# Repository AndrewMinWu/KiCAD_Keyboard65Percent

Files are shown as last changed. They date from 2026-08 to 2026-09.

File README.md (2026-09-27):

# Custom 65% Keyboard PCB





Untitled design

## Repository Structure

```text
├── Hardware/          # Schematic, PCB, and gerber files
├── Firmware/          # Firmware files
└── Libraries_And_Datasheets/              # Datasheets and libraries (from ai03) for keyboard parts. 
```

## Purpose & Motivation

When I was 15, I bought my first custom mechanical keyboard: a QK60 from Qwertykeys alongside Gateron yellow switches and some cheap keycaps from amazon. However, I encountered a problem when I accidently took out the PCB with the JST connector still plugged in, ripping the socket on the daughterboard (where the usb-c was). Devastated, this experience essentially brought me into PCB design through online guides and communities. 2 years later, with more PCB design experience, I decided to create my own 65% keyboard (my personal favorite form factor. Who uses the numpad anyways!?).     

## Design

### Component List (BOM)
1. ATmega32U4 8-bit AVR Microcontroller ([Datasheet](http://ww1.microchip.com/downloads/en/DeviceDoc/Atmel-7766-8-bit-AVR-ATmega16U4-32U4_Datasheet.pdf))
2. ECS-160 16.000MHz SMD Crystal 3225 4-Pin ([Datasheet](https://ecsxtal.com/store/pdf/ECX-32.pdf))
3. GCT USB4105-GF-A USB-C Receptacle 16P SMD RA ([Datasheet](https://gct.co/files/drawings/usb4105.pdf))
4. Keyboard Switches (MX, taken from ai03's library)
5. 1N4148 / 1N4148W Switching Diodes
6. Passives & Miscellaneous Hardware:
   - Capacitors (0805, Ceramic)
   - Resistors (0805)
   - Tactile Push Button (Reset Switch)

### PCB, Schematic, 3D Render

The full PCB was designed with KiCAD






## Firmware

The firmware for this keyboard is built using QMK. While the framework is C-based, configuring the board primarily involved utilizing the standard QMK file structure to define the hardware and layout:
* **`info.json` & `config.h`:** Keyboard matrix, MCU definitions, and hardware config
* **`rules.mk`:** Bootloader selection
* **`keymap.c`:** Keymap and layer definitions (able to change config with VIA)

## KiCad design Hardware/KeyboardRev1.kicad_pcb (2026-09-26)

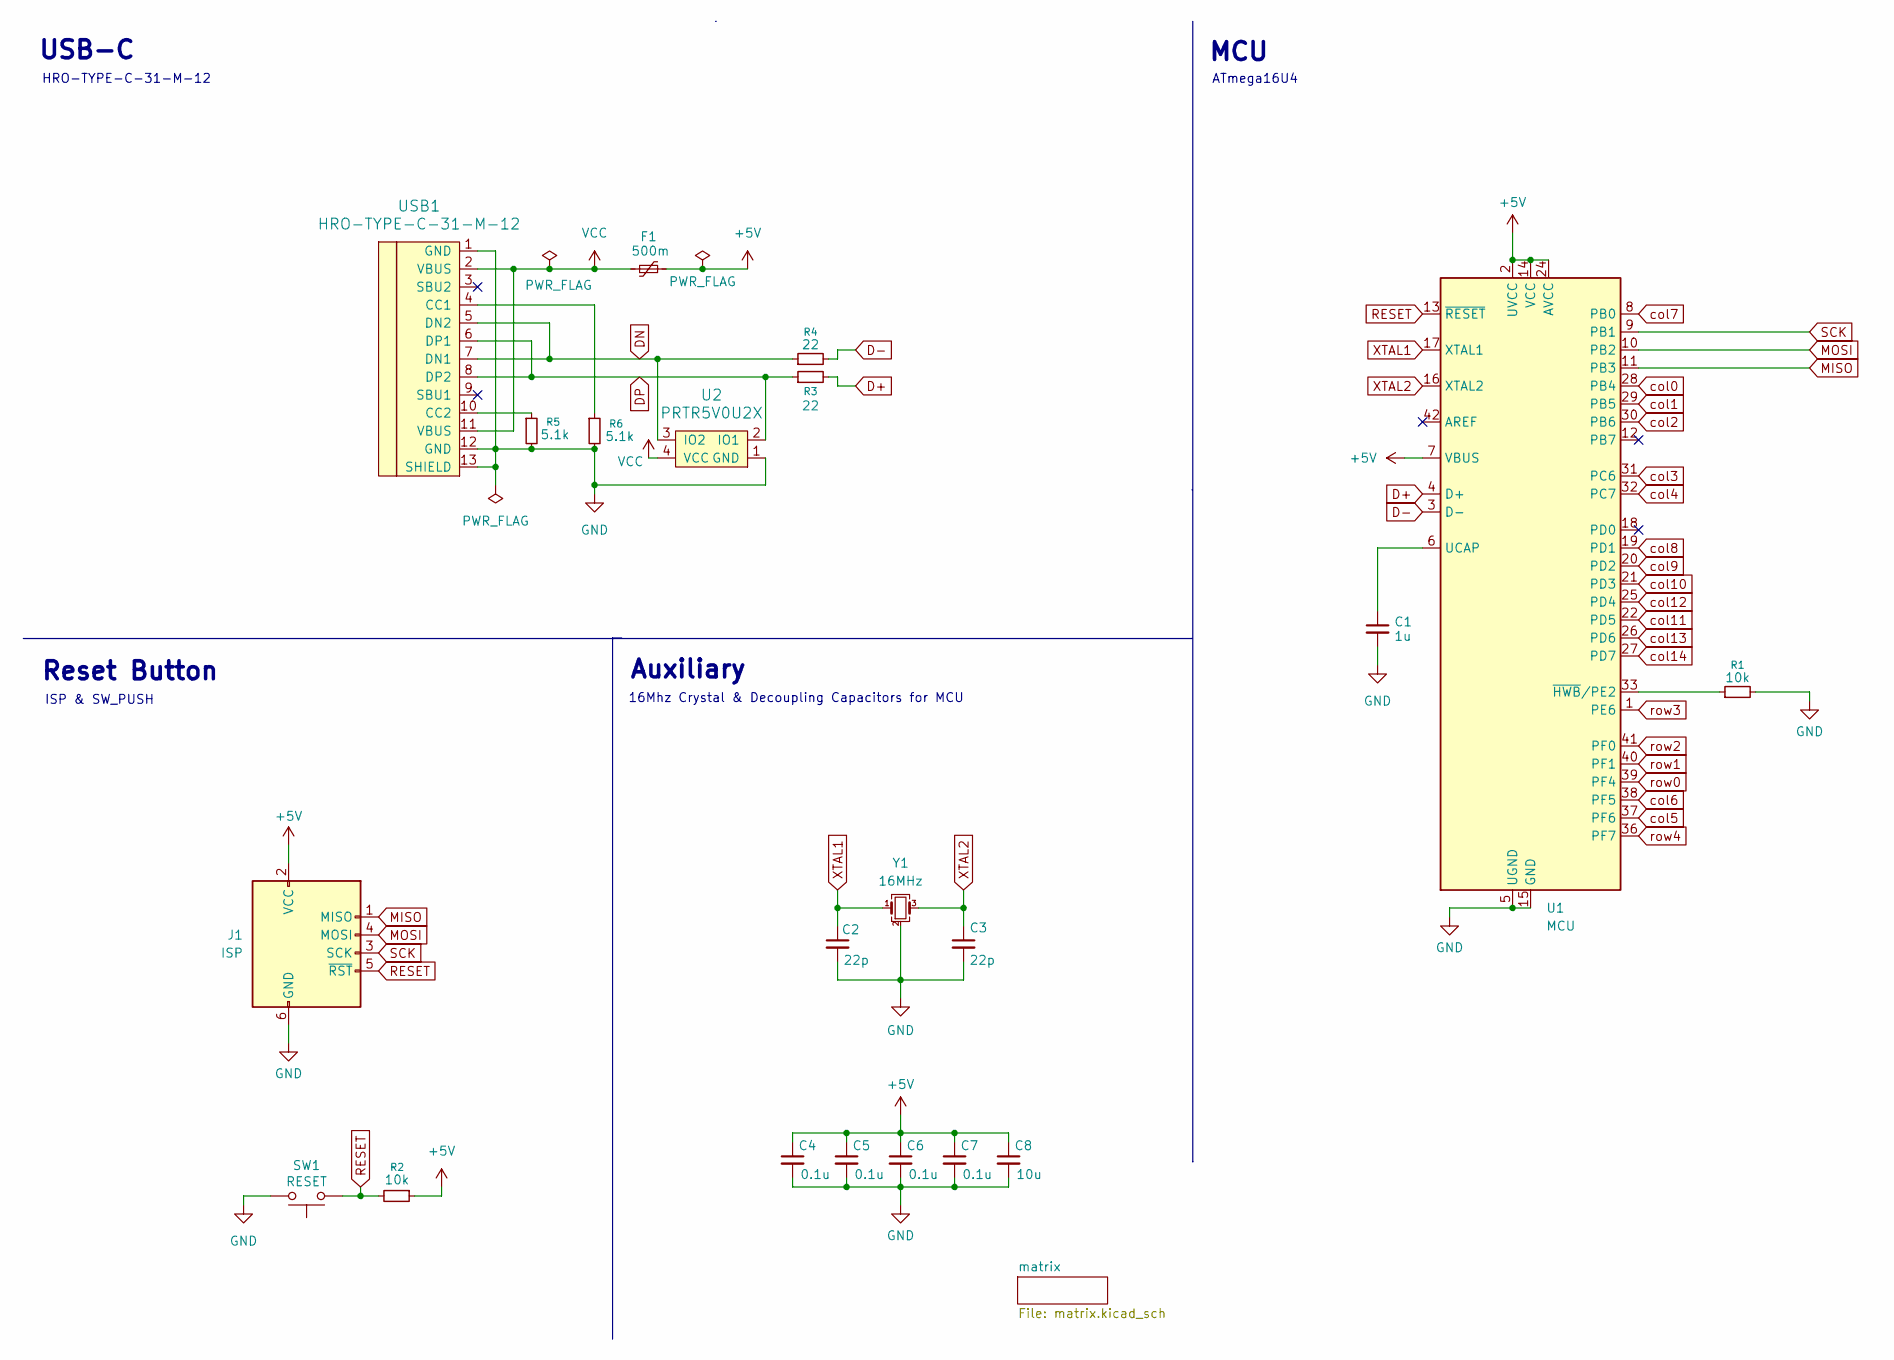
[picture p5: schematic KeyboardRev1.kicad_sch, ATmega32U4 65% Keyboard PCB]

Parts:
C1: 1u; C_0805_2012Metric_Pad1.18x1.45mm_HandSolder
C2, C3: 22p; C_0805_2012Metric_Pad1.18x1.45mm_HandSolder
C4, C5, C6, C7: 0.1u; C_0805_2012Metric_Pad1.18x1.45mm_HandSolder
C8: 10u; C_0805_2012Metric_Pad1.18x1.45mm_HandSolder
F1: 500m; Fuse_1206_3216Metric_Pad1.42x1.75mm_HandSolder
J1: ISP; Reset_Pretty-Mask
R1, R2: 10k; R_0805_2012Metric_Pad1.20x1.40mm_HandSolder
R3, R4: 22; R_0805_2012Metric_Pad1.20x1.40mm_HandSolder
R5, R6: 5.1k; R_0805_2012Metric_Pad1.20x1.40mm_HandSolder
SW1: RESET; SW_SPST_SKQG_WithStem
U1: MCU; TQFP-44_10x10mm_P0.8mm
U2: PRTR5V0U2X; SOT143B
USB1: HRO-TYPE-C-31-M-12; HRO-TYPE-C-31-M-12-HandSoldering
Y1: 16MHz; Crystal_SMD_3225-4Pin_3.2x2.5mm_HandSoldering

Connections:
+5V: C4.1, C5.1, C6.1, C7.1, C8.1, F1.2, J1.2 (VCC), R2.1, U1.2 (UVCC), U1.7 (VBUS), U1.14 (VCC), U1.24 (AVCC), U1.34 (VCC), U1.44 (AVCC)
D+: R3.2, U1.4 (D+)
D-: R4.2, U1.3 (D-)
DN: R4.1, U2.3 (IO2), USB1.5 (DN2), USB1.7 (DN1)
DP: R3.1, U2.2 (IO1), USB1.6 (DP1), USB1.8 (DP2)
GND: C1.2, C2.2, C3.2, C4.2, C5.2, C6.2, C7.2, C8.2, J1.6 (GND), R1.2, R5.2, R6.2, SW1.2, U1.5 (UGND), U1.15 (GND), U1.23 (GND), U1.35 (GND), U1.43 (GND), U2.1 (GND), USB1.1 (GND), USB1.12 (GND), USB1.13 (SHIELD), Y1.2 (G), Y1.4 (G)
MISO: J1.1 (MISO), U1.11 (PB3)
MOSI: J1.4 (MOSI), U1.10 (PB2)
unnamed: C1.1, U1.6 (UCAP)
unnamed: R1.1, U1.33 (~HWB/PE2)
unnamed: R6.1, USB1.4 (CC1)
unnamed: R5.1, USB1.10 (CC2)
RESET: J1.5 (~RST), R2.2, SW1.1, U1.13 (~RESET)
SCK: J1.3 (SCK), U1.9 (PB1)
VCC: F1.1, U2.4 (VCC), USB1.2 (VBUS), USB1.11 (VBUS)
XTAL1: C2.1, U1.17 (XTAL1), Y1.1
XTAL2: C3.1, U1.16 (XTAL2), Y1.3
col0: U1.28 (PB4); also elsewhere on the board
col1: U1.29 (PB5); also elsewhere on the board
col2: U1.30 (PB6); also elsewhere on the board
col3: U1.31 (PC6); also elsewhere on the board
col4: U1.32 (PC7); also elsewhere on the board
col5: U1.37 (PF6); also elsewhere on the board
col6: U1.38 (PF5); also elsewhere on the board
col7: U1.8 (PB0); also elsewhere on the board
col8: U1.19 (PD1); also elsewhere on the board
col9: U1.20 (PD2); also elsewhere on the board
col10: U1.21 (PD3); also elsewhere on the board
col11: U1.22 (PD5); also elsewhere on the board
col12: U1.25 (PD4); also elsewhere on the board
col13: U1.26 (PD6); also elsewhere on the board
col14: U1.27 (PD7); also elsewhere on the board
row0: U1.39 (PF4); also elsewhere on the board
row1: U1.40 (PF1); also elsewhere on the board
row2: U1.41 (PF0); also elsewhere on the board
row3: U1.1 (PE6); also elsewhere on the board
row4: U1.36 (PF7); also elsewhere on the board

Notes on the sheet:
16Mhz Crystal & Decoupling Capacitors for MCU
ATmega16U4
ISP & SW_PUSH
HRO-TYPE-C-31-M-12
Reset Button
USB-C
MCU
Auxiliary

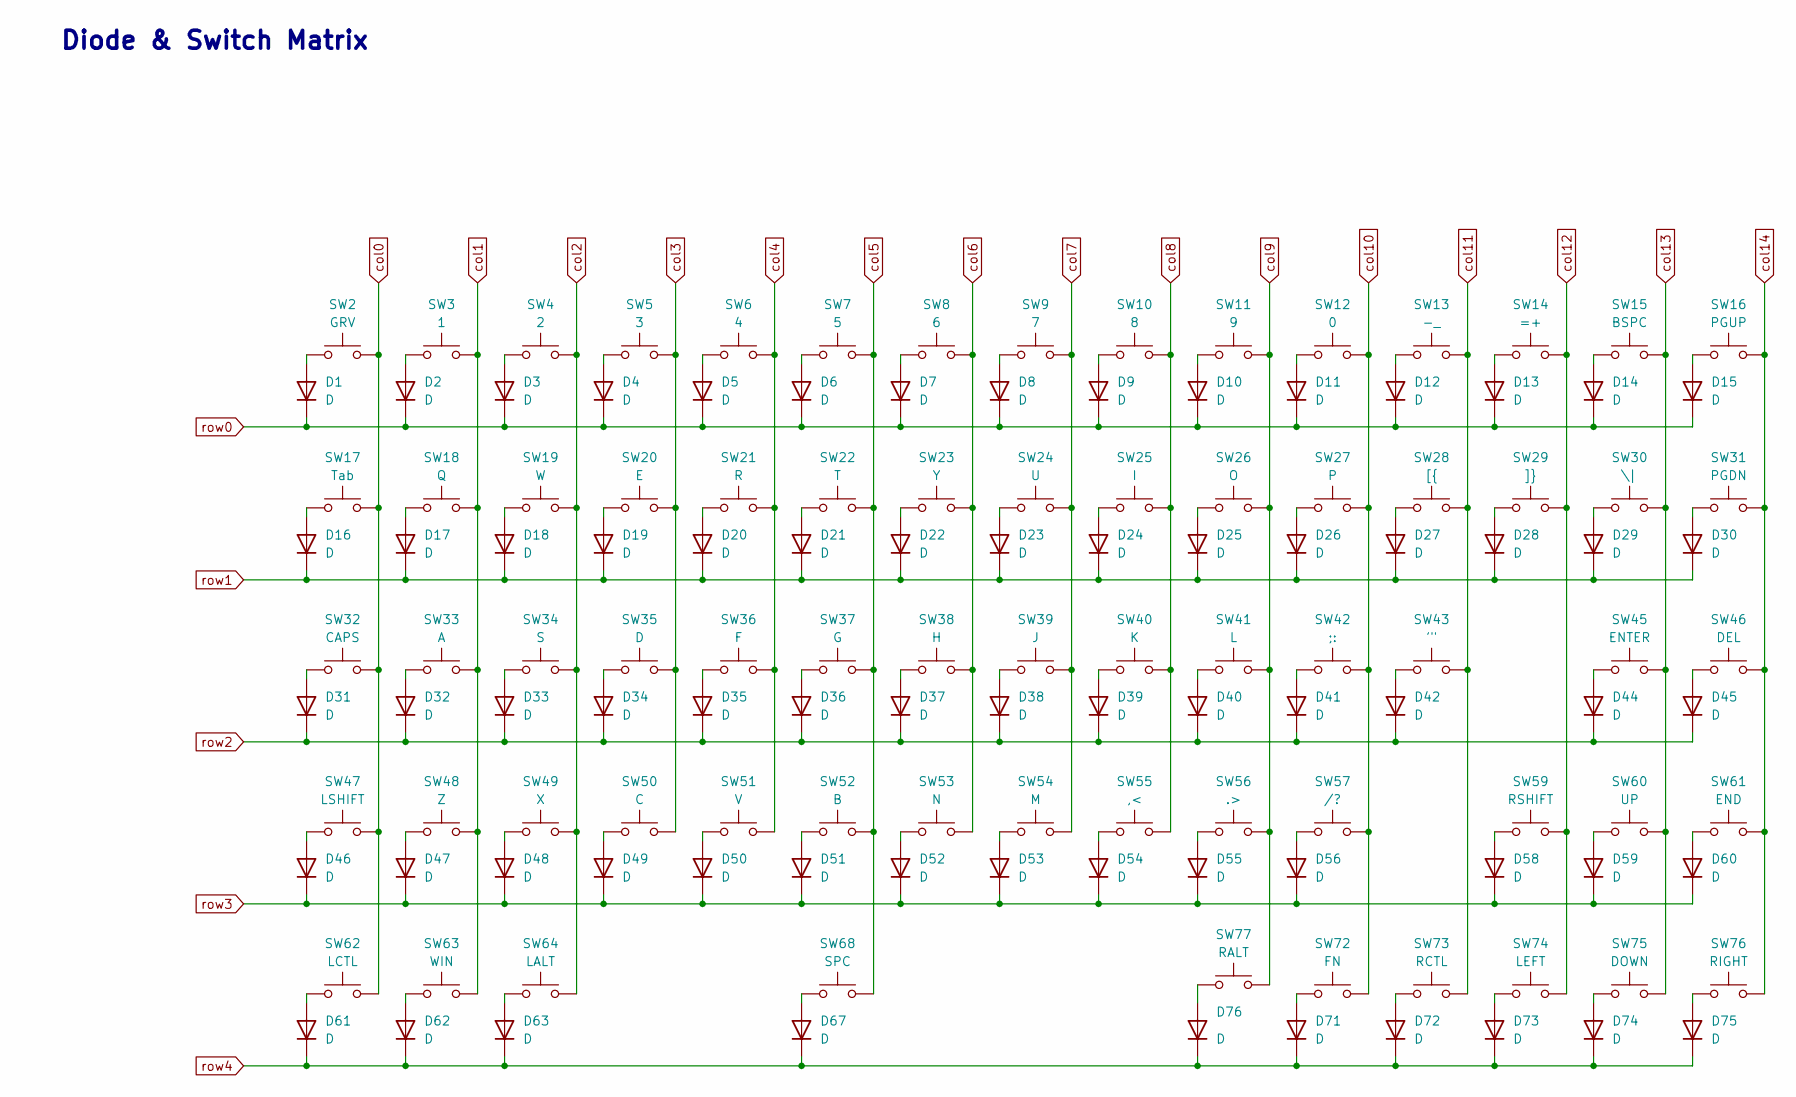
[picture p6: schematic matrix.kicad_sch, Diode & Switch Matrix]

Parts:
D1, D2, D3, D4, D5, D6, D7, D8, D9, D10, D11, D12, D13, D14, D15, D16, D17, D18, D19, D20, D21, D22, D23, D24, D25, D26, D27, D28, D29, D30, D31, D32, D33, D34, D35, D36, D37, D38, D39, D40, D41, D42, D44, D45, D46, D47, D48, D49, D50, D51, D52, D53, D54, D55, D56, D58, D59, D60, D61, D62, D63, D67, D71, D72, D73, D74, D75, D76: D; D_SOD-123
SW2: GRV; SW_Cherry_MX_1.00u_PCB
SW3: 1; SW_Cherry_MX_1.00u_PCB
SW4: 2; SW_Cherry_MX_1.00u_PCB
SW5: 3; SW_Cherry_MX_1.00u_PCB
SW6: 4; SW_Cherry_MX_1.00u_PCB
SW7: 5; SW_Cherry_MX_1.00u_PCB
SW8: 6; SW_Cherry_MX_1.00u_PCB
SW9: 7; SW_Cherry_MX_1.00u_PCB
SW10: 8; SW_Cherry_MX_1.00u_PCB
SW11: 9; SW_Cherry_MX_1.00u_PCB
SW12: 0; SW_Cherry_MX_1.00u_PCB
SW13: -_; SW_Cherry_MX_1.00u_PCB
SW14: =+; SW_Cherry_MX_1.00u_PCB
SW15: BSPC; SW_Cherry_MX_2.00u_PCB
SW16: PGUP; SW_Cherry_MX_1.00u_PCB
SW17: Tab; SW_Cherry_MX_1.50u_PCB
SW18: Q; SW_Cherry_MX_1.00u_PCB
SW19: W; SW_Cherry_MX_1.00u_PCB
SW20: E; SW_Cherry_MX_1.00u_PCB
SW21: R; SW_Cherry_MX_1.00u_PCB
SW22: T; SW_Cherry_MX_1.00u_PCB
SW23: Y; SW_Cherry_MX_1.00u_PCB
SW24: U; SW_Cherry_MX_1.00u_PCB
SW25: I; SW_Cherry_MX_1.00u_PCB
SW26: O; SW_Cherry_MX_1.00u_PCB
SW27: P; SW_Cherry_MX_1.00u_PCB
SW28: [{; SW_Cherry_MX_1.00u_PCB
SW29: ]}; SW_Cherry_MX_1.00u_PCB
SW30: \|; SW_Cherry_MX_1.50u_PCB
SW31: PGDN; SW_Cherry_MX_1.00u_PCB
SW32: CAPS; SW_Cherry_MX_1.75u_PCB
SW33: A; SW_Cherry_MX_1.00u_PCB
SW34: S; SW_Cherry_MX_1.00u_PCB
SW35: D; SW_Cherry_MX_1.00u_PCB
SW36: F; SW_Cherry_MX_1.00u_PCB
SW37: G; SW_Cherry_MX_1.00u_PCB
SW38: H; SW_Cherry_MX_1.00u_PCB
SW39: J; SW_Cherry_MX_1.00u_PCB
SW40: K; SW_Cherry_MX_1.00u_PCB
SW41: L; SW_Cherry_MX_1.00u_PCB
SW42: ;:; SW_Cherry_MX_1.00u_PCB
SW43: '"; SW_Cherry_MX_1.00u_PCB
SW45: ENTER; SW_Cherry_MX_2.25u_PCB
SW46: DEL; SW_Cherry_MX_1.00u_PCB
SW47: LSHIFT; SW_Cherry_MX_2.25u_PCB
SW48: Z; SW_Cherry_MX_1.00u_PCB
SW49: X; SW_Cherry_MX_1.00u_PCB
SW50: C; SW_Cherry_MX_1.00u_PCB
SW51: V; SW_Cherry_MX_1.00u_PCB
SW52: B; SW_Cherry_MX_1.00u_PCB
SW53: N; SW_Cherry_MX_1.00u_PCB
SW54: M; SW_Cherry_MX_1.00u_PCB
SW55: ,<; SW_Cherry_MX_1.00u_PCB
SW56: .>; SW_Cherry_MX_1.00u_PCB
SW57: /?; SW_Cherry_MX_1.00u_PCB
SW59: RSHIFT; SW_Cherry_MX_1.75u_PCB
SW60: UP; SW_Cherry_MX_1.00u_PCB
SW61: END; SW_Cherry_MX_1.00u_PCB
SW62: LCTL; SW_Cherry_MX_1.25u_PCB
SW63: WIN; SW_Cherry_MX_1.25u_PCB
SW64: LALT; SW_Cherry_MX_1.25u_PCB
SW68: SPC; SW_Cherry_MX_6.25u_PCB
SW72: FN; SW_Cherry_MX_1.00u_PCB
SW73: RCTL; SW_Cherry_MX_1.00u_PCB
SW74: LEFT; SW_Cherry_MX_1.00u_PCB
SW75: DOWN; SW_Cherry_MX_1.00u_PCB
SW76: RIGHT; SW_Cherry_MX_1.00u_PCB
SW77: RALT; SW_Cherry_MX_1.00u_PCB

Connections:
unnamed: D1.2 (A), SW2.1
unnamed: D2.2 (A), SW3.1
unnamed: D3.2 (A), SW4.1
unnamed: D4.2 (A), SW5.1
unnamed: D5.2 (A), SW6.1
unnamed: D6.2 (A), SW7.1
unnamed: D7.2 (A), SW8.1
unnamed: D8.2 (A), SW9.1
unnamed: D9.2 (A), SW10.1
unnamed: D10.2 (A), SW11.1
unnamed: D11.2 (A), SW12.1
unnamed: D12.2 (A), SW13.1
unnamed: D13.2 (A), SW14.1
unnamed: D14.2 (A), SW15.1
unnamed: D15.2 (A), SW16.1
unnamed: D16.2 (A), SW17.1
unnamed: D17.2 (A), SW18.1
unnamed: D18.2 (A), SW19.1
unnamed: D19.2 (A), SW20.1
unnamed: D20.2 (A), SW21.1
unnamed: D21.2 (A), SW22.1
unnamed: D22.2 (A), SW23.1
unnamed: D23.2 (A), SW24.1
unnamed: D24.2 (A), SW25.1
unnamed: D25.2 (A), SW26.1
unnamed: D26.2 (A), SW27.1
unnamed: D27.2 (A), SW28.1
unnamed: D28.2 (A), SW29.1
unnamed: D29.2 (A), SW30.1
unnamed: D30.2 (A), SW31.1
unnamed: D31.2 (A), SW32.1
unnamed: D32.2 (A), SW33.1
unnamed: D33.2 (A), SW34.1
unnamed: D34.2 (A), SW35.1
unnamed: D35.2 (A), SW36.1
unnamed: D36.2 (A), SW37.1
unnamed: D37.2 (A), SW38.1
unnamed: D38.2 (A), SW39.1
unnamed: D39.2 (A), SW40.1
unnamed: D40.2 (A), SW41.1
unnamed: D41.2 (A), SW42.1
unnamed: D42.2 (A), SW43.1
unnamed: D44.2 (A), SW45.1
unnamed: D45.2 (A), SW46.1
unnamed: D46.2 (A), SW47.1
unnamed: D47.2 (A), SW48.1
unnamed: D48.2 (A), SW49.1
unnamed: D49.2 (A), SW50.1
unnamed: D50.2 (A), SW51.1
unnamed: D51.2 (A), SW52.1
unnamed: D52.2 (A), SW53.1
unnamed: D53.2 (A), SW54.1
unnamed: D54.2 (A), SW55.1
unnamed: D55.2 (A), SW56.1
unnamed: D56.2 (A), SW57.1
unnamed: D58.2 (A), SW59.1
unnamed: D59.2 (A), SW60.1
unnamed: D60.2 (A), SW61.1
unnamed: D61.2 (A), SW62.1
unnamed: D62.2 (A), SW63.1
unnamed: D63.2 (A), SW64.1
unnamed: D67.2 (A), SW68.1
unnamed: D71.2 (A), SW72.1
unnamed: D72.2 (A), SW73.1
unnamed: D73.2 (A), SW74.1
unnamed: D74.2 (A), SW75.1
unnamed: D75.2 (A), SW76.1
unnamed: D76.2 (A), SW77.1
col0: SW2.2, SW17.2, SW32.2, SW47.2, SW62.2; also elsewhere on the board
col1: SW3.2, SW18.2, SW33.2, SW48.2, SW63.2; also elsewhere on the board
col2: SW4.2, SW19.2, SW34.2, SW49.2, SW64.2; also elsewhere on the board
col3: SW5.2, SW20.2, SW35.2, SW50.2; also elsewhere on the board
col4: SW6.2, SW21.2, SW36.2, SW51.2; also elsewhere on the board
col5: SW7.2, SW22.2, SW37.2, SW52.2, SW68.2; also elsewhere on the board
col6: SW8.2, SW23.2, SW38.2, SW53.2; also elsewhere on the board
col7: SW9.2, SW24.2, SW39.2, SW54.2; also elsewhere on the board
col8: SW10.2, SW25.2, SW40.2, SW55.2; also elsewhere on the board
col9: SW11.2, SW26.2, SW41.2, SW56.2, SW77.2; also elsewhere on the board
col10: SW12.2, SW27.2, SW42.2, SW57.2, SW72.2; also elsewhere on the board
col11: SW13.2, SW28.2, SW43.2, SW73.2; also elsewhere on the board
col12: SW14.2, SW29.2, SW59.2, SW74.2; also elsewhere on the board
col13: SW15.2, SW30.2, SW45.2, SW60.2, SW75.2; also elsewhere on the board
col14: SW16.2, SW31.2, SW46.2, SW61.2, SW76.2; also elsewhere on the board
row0: D1.1 (K), D2.1 (K), D3.1 (K), D4.1 (K), D5.1 (K), D6.1 (K), D7.1 (K), D8.1 (K), D9.1 (K), D10.1 (K), D11.1 (K), D12.1 (K), D13.1 (K), D14.1 (K), D15.1 (K); also elsewhere on the board
row1: D16.1 (K), D17.1 (K), D18.1 (K), D19.1 (K), D20.1 (K), D21.1 (K), D22.1 (K), D23.1 (K), D24.1 (K), D25.1 (K), D26.1 (K), D27.1 (K), D28.1 (K), D29.1 (K), D30.1 (K); also elsewhere on the board
row2: D31.1 (K), D32.1 (K), D33.1 (K), D34.1 (K), D35.1 (K), D36.1 (K), D37.1 (K), D38.1 (K), D39.1 (K), D40.1 (K), D41.1 (K), D42.1 (K), D44.1 (K), D45.1 (K); also elsewhere on the board
row3: D46.1 (K), D47.1 (K), D48.1 (K), D49.1 (K), D50.1 (K), D51.1 (K), D52.1 (K), D53.1 (K), D54.1 (K), D55.1 (K), D56.1 (K), D58.1 (K), D59.1 (K), D60.1 (K); also elsewhere on the board
row4: D61.1 (K), D62.1 (K), D63.1 (K), D67.1 (K), D71.1 (K), D72.1 (K), D73.1 (K), D74.1 (K), D75.1 (K), D76.1 (K); also elsewhere on the board

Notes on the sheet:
Diode & Switch Matrix

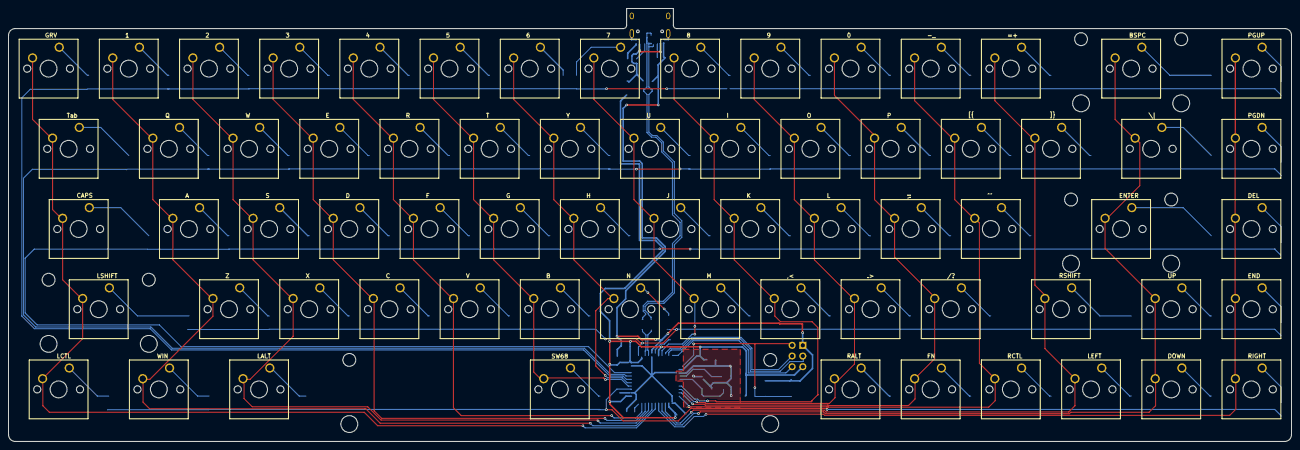
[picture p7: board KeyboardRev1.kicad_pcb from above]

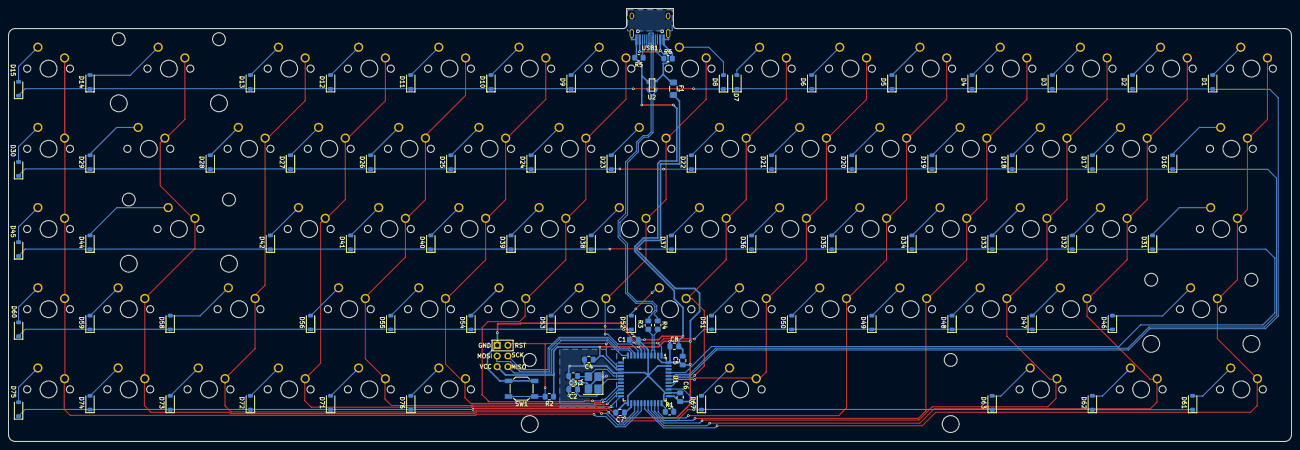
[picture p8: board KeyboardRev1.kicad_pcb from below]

Board: 2 copper layers, 304.8 x 102.9 mm, 157 parts (89 on the bottom side), 105 nets.

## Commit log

2026-08-29 Uploaded all required libraries
    [HRO TYPE-C-31-M-12.step, JST-SR-3.step, JST-SR-4.step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]
2026-08-29 Electronic Schema Complete
    [KeyboardRev1.kicad_pcb, KeyboardRev1.kicad_sch]
2026-08-30 PCB Design Started.
    [KeyboardRev1.kicad_pcb, KeyboardRev1.kicad_sch, matrix.kicad_sch]
2026-08-31 Updated PCB, Currently finishing cooper traces
    [KeyboardRev1.kicad_pcb]
2026-09-01 Final Design
    Finished the D-/D+ (Differential Pair) on the USB, finished all silkscreens, and finalized all cooper traces.
    [KeyboardRev1.kicad_pcb, KeyboardRev1.kicad_sch, matrix.kicad_sch]
2026-09-26 Updated File organization
    [KeyboardRev1.kicad_pcb, KeyboardRev1.kicad_sch, matrix.kicad_sch]
